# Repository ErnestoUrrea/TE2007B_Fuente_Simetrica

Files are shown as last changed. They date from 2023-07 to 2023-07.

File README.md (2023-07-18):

# Fuente de poder simétrica de regulación lineal
Circuito de filtrado y regulacion para una fuente de poder de 12 VDC, 0.5 A, con protección de sobrecarga e interruptor de encendido/apagado. Diseñada para la unidad de formacion **TE2007B**.<br>

**Equipo:** <br>
César Aurelio Martínez Rodríguez<br>
Mario Alberto Sánchez López<br>
Ernesto Enrique Urrea López<br>

## Especificaciones

El circuito se diseñó para cumplir con las siguientes especificaciones:
- Voltaje de salida +12 volts y -12 volts regulados
- Factor de rizo máximo antes del regulador del 6%
- Regulación de carga y de línea máxima de 10mv
- Corriente de salida máxima de 500mA
- Protección de sobrecorriente
- Interruptor 
- Led indicador
- Terminales de salida

La entrada al circuito de filtrado y regulación es proporcionada por un transformador con derivación central y salida de 30.2 Vrms.

## Diagrama esquemático
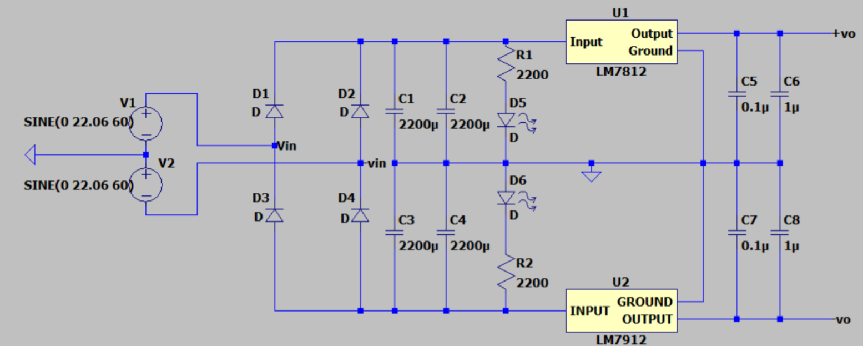
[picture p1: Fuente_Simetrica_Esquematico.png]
Diagrama esquemático del circuito de filtrado y regulación


## Vista 3D
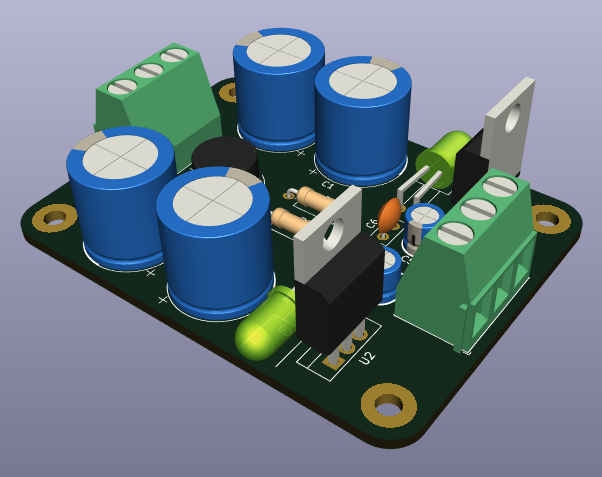
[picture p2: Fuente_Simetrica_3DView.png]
Vista 3D del PCB de la fuente ensamblado


## PCB Ensamblada
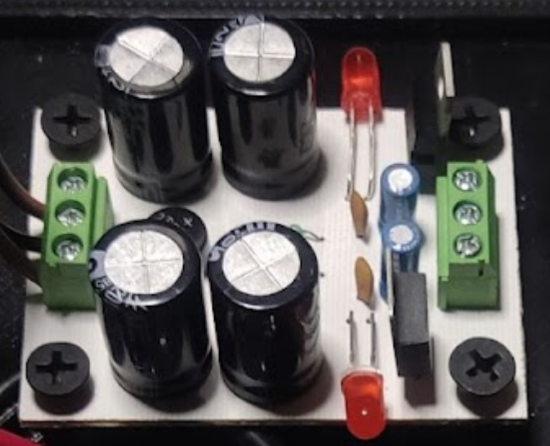
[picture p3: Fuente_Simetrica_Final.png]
Imagen de la PCB Ensamblada


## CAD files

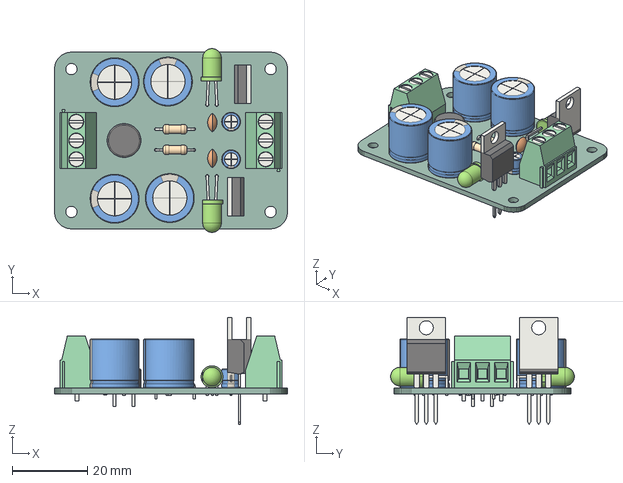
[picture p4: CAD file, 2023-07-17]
Fuente_TE2007B_Simetrica.step
62.0 x 48.9 x 28.5 mm
Fuente_TE2007B_Simetrica PCB

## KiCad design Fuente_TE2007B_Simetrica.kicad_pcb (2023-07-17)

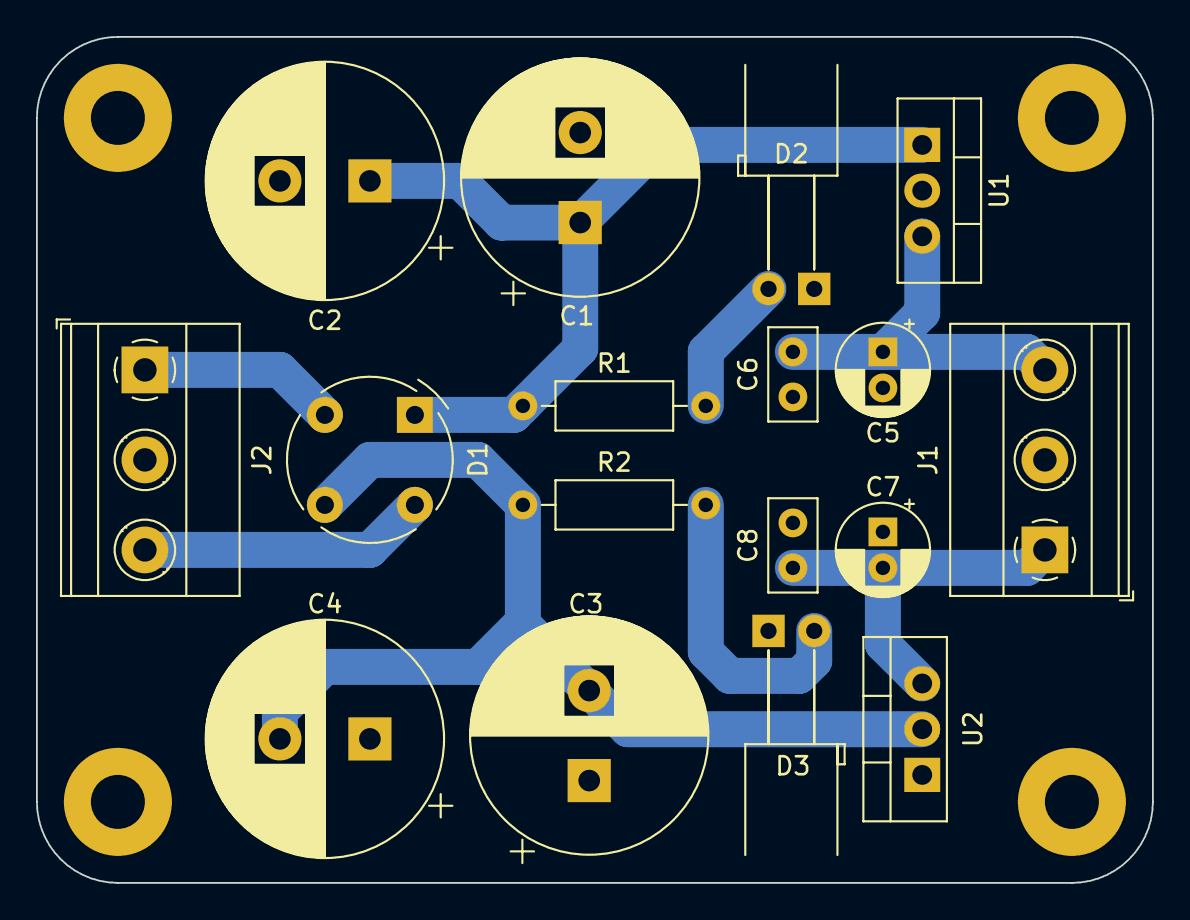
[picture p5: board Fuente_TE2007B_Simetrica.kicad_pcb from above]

Board: 2 copper layers, 62.0 x 47.0 mm, 21 parts (0 on the bottom side), 9 nets.

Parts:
C1, C2, C3, C4: 2200 u; CP_Radial_D13.0mm_P5.00mm
C5, C7: 1 u; CP_Radial_D5.0mm_P2.00mm
C6, C8: 0.1 u; C_Disc_D5.0mm_W2.5mm_P2.50mm
D1: D_Bridge_+A-A; Diode_Bridge_Round_D9.0mm
D2, D3: LED; LED_D5.0mm_Horizontal_O6.35mm_Z3.0mm
H1, H2, H3, H4: MountingHole_Pad; MountingHole_3mm_Pad
J1, J2: Screw_Terminal_01x03; TerminalBlock_Phoenix_MKDS-1,5-3_1x03_P5.00mm_Horizontal
R1, R2: 1.1 k; R_Axial_DIN0207_L6.3mm_D2.5mm_P10.16mm_Horizontal
U1: LM7812_TO220; TO-220-3_Vertical
U2: LM7912_TO220; TO-220-3_Vertical

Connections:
GND: C1.2, C2.2, C3.1, C4.1, C5.2, C6.2, C7.1, C8.1, D2.1 (K), D3.1 (K), H1.1, H2.1, H3.1, H4.1, J1.2, J2.2, U1.2 (GND), U2.1 (GND)
NFILT: C3.2, C4.2, D1.3 (-), R2.1, U2.2 (VI)
unnamed: D2.2 (A), R1.2
unnamed: D3.2 (A), R2.2
PFILT: C1.1, C2.1, D1.1 (+), R1.1, U1.1 (VI)
VOUT+: C5.1, C6.1, J1.3, U1.3 (VO)
VOUT-: C7.2, C8.2, J1.1, U2.3 (VO)
X1: D1.2, J2.1
X3: D1.4, J2.3

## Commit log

2023-07-17 Circuit diagram image
2023-07-18 Assembled pcb image
